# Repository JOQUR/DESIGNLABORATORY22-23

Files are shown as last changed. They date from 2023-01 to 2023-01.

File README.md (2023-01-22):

# DesignLab-BabaJaga
Repository for BabaJaga project created as part of Design Laboratory Classes
Welcome

BabaJaga Rules:
------------------
* 1. Participants:
For each game we need at least 3 participants, two players, and oone supervisor, which will start, and stop game
* 2. Duration
1min-3min for each round
* 3. How to Play?:
Supervisor using his mobile phone sets the game. Players have to stand in front of PIRs in the same distane, to give each players equal chances.
Then the game starts. Supervisor can use feature "Baba Jaga patrzy". At this moments players cannot move, if anyone moves, he loses round.
After reaching game board, player have to press the button. Then the game stops, and we have a winner.

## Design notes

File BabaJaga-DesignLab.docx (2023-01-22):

| AGH University of Science and Technology

Report on the project

Baba Jaga patrzy

For classes

Design Laboratory

Elektronika i Telekomunikacja, 3rd year

Paweł, Kierzek, Paweł Tymoczko, Mariusz Furtek

Coordinator: Dr inż. Jacek Stępień

22.01.2023

# 1. Project’s goal

Goal of the project was to create hardware-software system which is the implementation of the real-life game “Baba Jaga Patrzy”.

# 2. Design assumptions

  2.1. System functionality

Game system is divided into 2 modules communicating via common Bluetooth interface:

- Game Module - core of the game, if initialized can be in 2 states:
  - BABA_JAGA_PATRZY – detects players movement and reports it,
  - BABA_JAGA_NIE_PATRZY – detects pushed buttons and reports it.
- Control Module – allows to send 4 different messages to the Game Module START, STOP, BABA_JAGA_PATRZY, BABA_JAGA_NIE_PATRZY. Depending on the message type specified action are taken by another module:
  - START – initialize the game,
  - STOP – finish the game,
  - BABA_JAGA_PATRZY – change the game to “BABA_JAGA_PATRZY” state,
  - BABA_JAGA_NIE_PATRZY - change the game to “BABA_JAGA_NIE_ PATRZY” state.

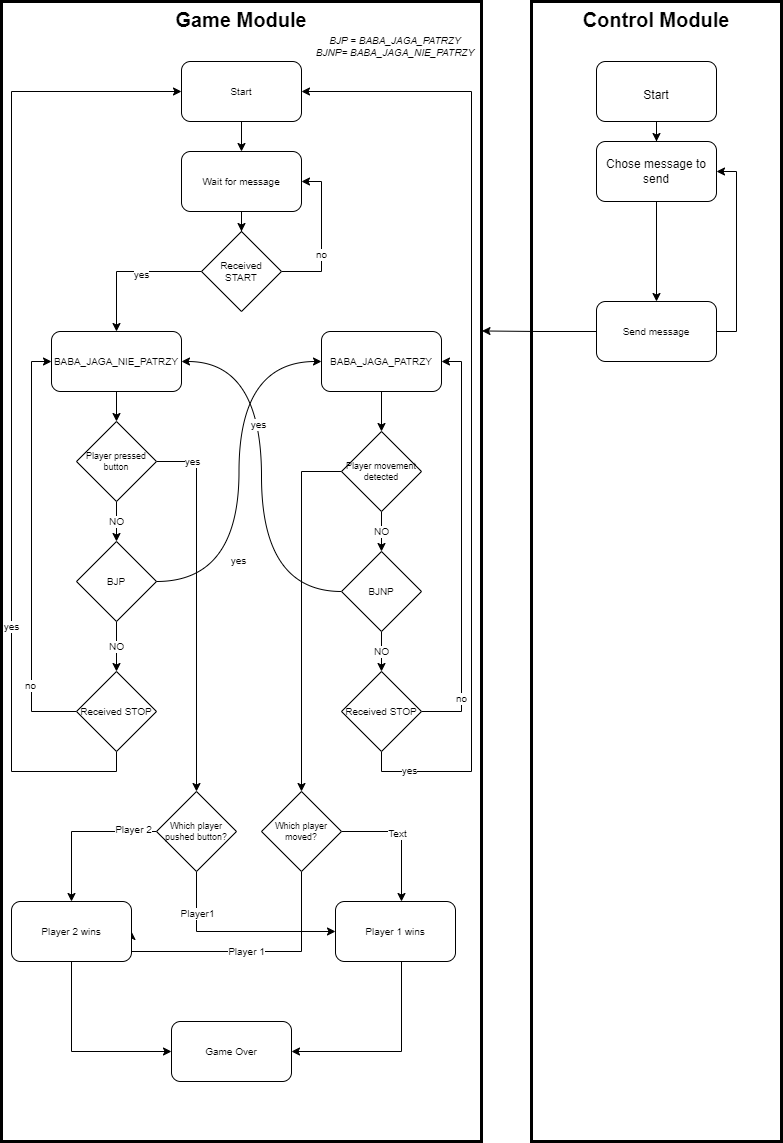
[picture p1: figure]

Picture 1. Game mechanism block diagram.

  2.2. User Interface

The game is designed for 3 players: 2 contestants and a game master.

The game master is responsible for controlling the game flow: starting/stopping the game and enabling/disabling movement detection.

If game master initializes the game, green diode lights up and keep on until the end of the game.

Contestant’s goal is to arrive to the location of the button and to push it before another player – first to do so wins. Contestant must watch out for the state of red diode. If it lights up, both players must stop and do not move. Otherwise, the contestant whose movement is detected, loses.

After player pushing the button or sensors detecting movement, high pitch sound is to be heard. One of two diodes (yellow corresponding to player no1 and green for player 2) lights up to inform who is the game winner.

  2.3. Hardware

Table 1. Electronic elements chosen for project implementation.

Element name | Module | Application
STM32 NUCLEO-L432KC | Game Module | Controls game flow, PIR movement detectors and all other game peripherals (buzzer, diodes), receives data from HC06 Bluetooth module
FRDM-KL05ZJ | Control Module | Sends messages to Bluetooth module HC05, based on pressed buttons, displays data on lcd
HC-05 BLUETOOTH MODULE | Control Module | Master of Bluetooth communication, transmit messages from Control Module to Game Module
HC-06 BLUETOOTH MODULE | Game Module | Slave of Bluetooth communication, receive messages from Control Module
HC-SR501 PIR MOTION DETECTOR | Game Module | Detects movement when Game Module is in BABA_JAGA_PATRZY state and reports game rules violation
HCM12-X BUZZER | Game module | Plays sound when game ends
LCD1602A (with I2C expander) | Control Module | Displays messages, currently transmitted to Game Module
HW-834 4x4 BUTTON MATRIX | Control Module | Pressing button corresponds to sending predefined messages

Datasheets of elements are to be found in project’s Git repository. Apart from listed components, other such as diodes, push button and resistors were used.

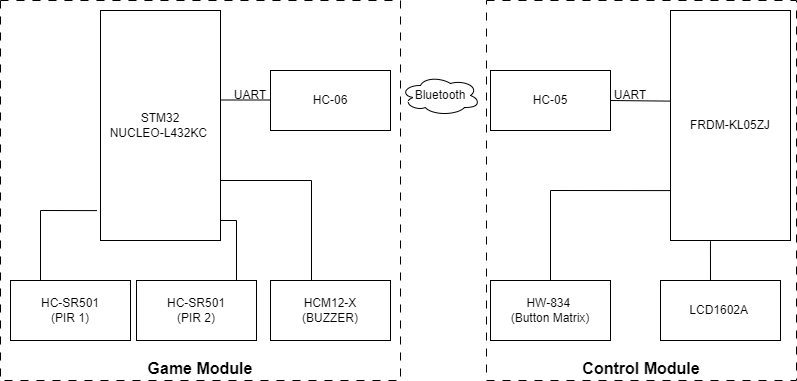
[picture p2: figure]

Picture 2. Project’s modules block diagram.

  2.4. Software Main functionality of Control Module’s program is to handle button matrix interrupts and transmit messages over UART to HC-05 Bluetooth module.

Game module’s program:

- handles interrupts from PIRs which detects players’ movement,
- lights up appropriate diode to inform players about game status,
- receives messages over UART form HC-06 and based on the input turns on or off PIRs’ interrupts.

Both Game Module and Control Module application were chosen to be written in C, using STM32CubeIDE.

# 3. Project Realization

Both modules have been designed according to presumptions described in previous part 2. Design assumptions. However, during integration process issue concerning HC05 and HC06 modules has occurred. There has been problem with entering command mode on Bluetooth modules, thus with pairing device for wireless communication. To mitigate impact on whole project and to ensure feature of wireless game controlling, new solution has been proposed: to substitute intended Control Module with simple mobile android application.

Created app has all assumed functionality and from user perspective is easier to use.

  3.1. Game Module’s electronic schematic and PCB layout

Game Module’s elements were connected according to the schematic in the Picture 3.

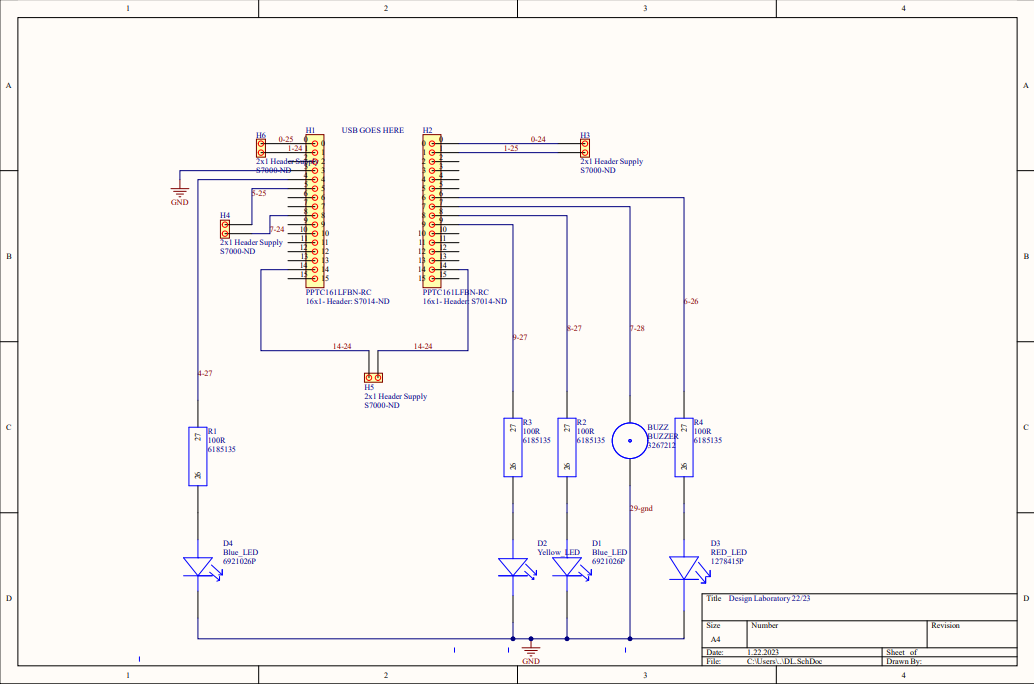
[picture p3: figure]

Picture 3. Game Module electronic schematic

On the schematic both PIRs and push buttons power on have not been put. PIRs are powered on according to the datasheet specification to +5V and GND and push buttons are connected to the power supply +5V.

Based on the electronic schematic attempt at creating PCB layout has been made. Unfortunately, created layout correctness has not been confirmed with necessary analysis.

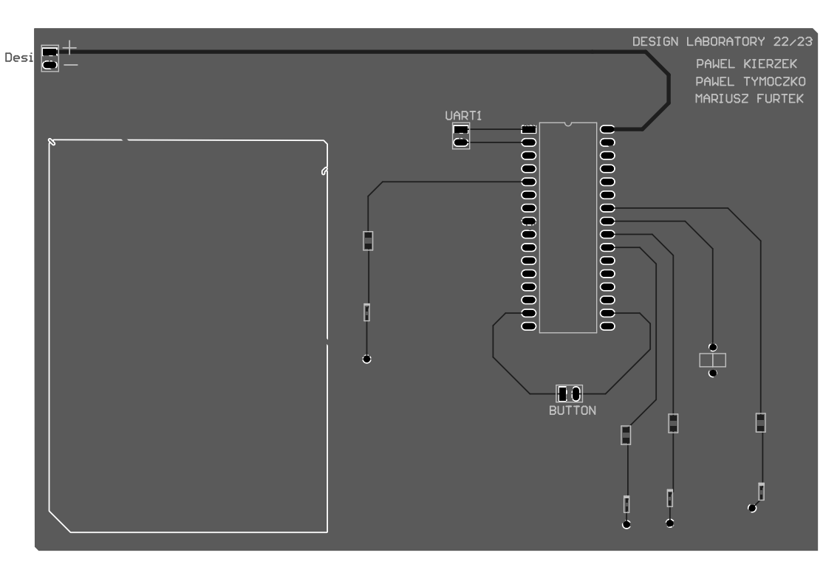
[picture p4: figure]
Obraz zawierający tekst, sprzęt elektroniczny Opis wygenerowany automatycznie

Picture 4. PCB Layout attempt

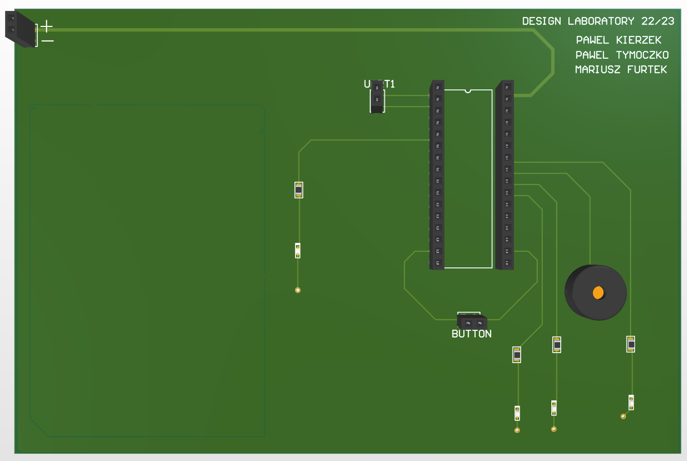
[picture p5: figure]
Brak opisu.

Picture 5. Expected frontside PCB 3D visualization.

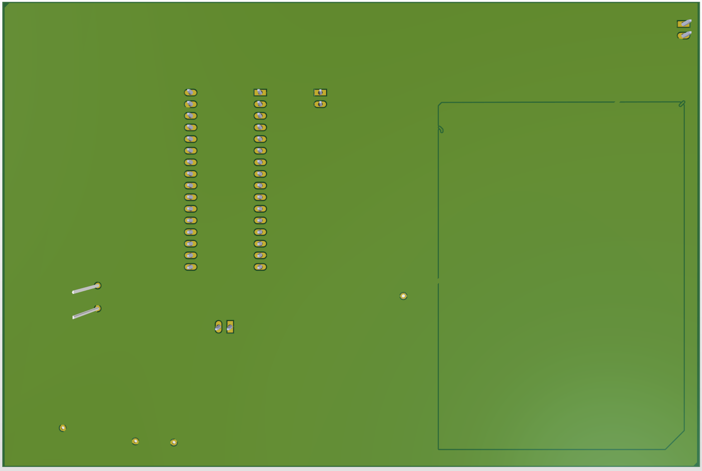
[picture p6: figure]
Brak opisu.

Picture 6. Expected backside PCB 3D visualization.

  3.2. Game module software

Table 2. Used GPIO pins, their configuration mode and functionality.

Pin name | User labels | Mode | Function
PB0 | PIR_SIG1 | External Interrupt Mode with rising edge trigger detection | Receives information about detected movement by PIR1
PB1 | PIR_SIG2 | External Interrupt Mode with rising edge trigger detection | Receives information about detected movement by PIR2
PA3 | PIR_OUT1 | Output Push Pull | Lights up yellow diode if player 1 wins
PA4 | PIR_OUT2 | Output Push Pull | Lights up green diode if player 2 wins
PA6 | BABA_JAGA_PATRZY | Output Push Pull | Lights up red diode if Game Module is in BABA_JAGA_PATRZY mode
PA5 | BUZZER | Output Push Pull | Generate sound if game finishes
PA12 | GAME_ON | Output Push Pull | Lights up green diode when game is initialized
PA10 | USART1_RX | UART | Enables Bluetooth communication with Control Module
PA9 | USART1_TX | UART
PB3 | BUTTON_1 | External Interrupt Mode with rising edge trigger detection | Receives information if player no. 1 pressed button
PB4 | BUTTON_2 | External Interrupt Mode with rising edge trigger detection | Receives information if player no. 2 pressed button

All pins above are configured to the appropriate mode and initialized in Game Module program’s main function.

In the program game loop, program is waiting for new messages from UART1. If new message is the same as one of defined below, it takes corresponding action:

- START – ‘A’: initializes the game, reset all diode pins and buzzer pin, clear players’ score, light up GAME_ON diode, set state to BABA_JAGA_NIE_PATRZY,
- STOP – ‘B’: finishes game, reset all diode pins and buzzer pin, clear players’ score,
- BABA_JAGA_PATRZY – ‘C’: enables PIRs interrupts to allow movement detection,
- BABA_JAGA_NIE_PATRZY – ‘D’: disable PIRs interrupts,
  3.3. Control Module mobile application

The application has been created using MIT App Inventor online tool in Scratch programming language. It allows to communicate with HC-05 module and send defined Game Module messages.

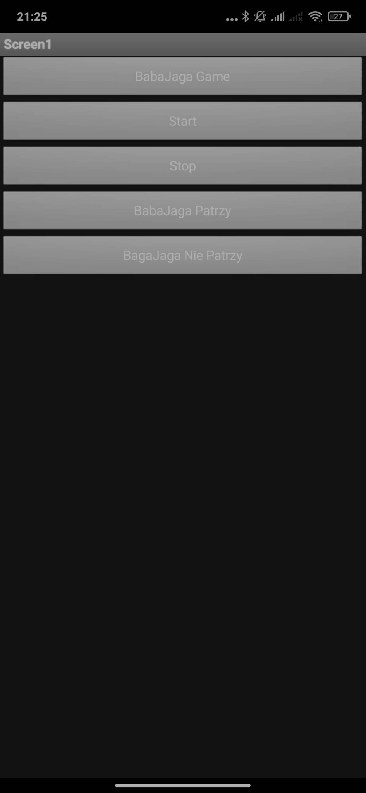
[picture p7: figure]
Brak opisu.

Picture 7. Screen shot of Control Module App GUI

  3.4. Workflow and labor division

The project’s workflow and labor division are to be found in the spreadsheet named workflow.xslx in git repository.

For project management and team organization Trello Kanban board was used.

# 4. Resources

  4.1. Project resources
- GIT repository: https://github.com/Pawlicho/DesignLab-BabaJaga
- Trello Kanban board: https://trello.com/b/rw4OTdqo/baba-jaga-patrzy
  4.2. External sources
- MIT App Inventor: https://appinventor.mit.edu/
- CAD footprints: https://www.digikey.pl/

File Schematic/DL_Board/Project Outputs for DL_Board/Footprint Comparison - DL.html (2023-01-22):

Altium customize

# Footprint Comparison Report

Date: | | 22.01.2023
Time: | | 23:47:13
Elapsed Time: | | 00:00:00
Filename: | | C:\Users\PKier\OneDrive\Pulpit\Design Lab\DesignLab-BabaJaga\Schematic\DL_Board\DL.PcbDoc

## Contents

Contents

Components Status Summary

Matched Components List

Missing PCB Components List

## Components Status Summary

## Matched Components List

Designator | Footprint | Footprint reference | Footprint to reference Library
Designator8 | DIP32 | DIP32 | C:\Users\PKier\OneDrive\Pulpit\Design Lab\DesignLab-BabaJaga\Schematic\DL_Board\DL.PcbLib
Designator9 | R0805 | R0805 | C:\Users\PKier\OneDrive\Pulpit\Design Lab\DesignLab-BabaJaga\Schematic\DL_Board\DL.PcbLib
Designator10 | R0805 | R0805 | C:\Users\PKier\OneDrive\Pulpit\Design Lab\DesignLab-BabaJaga\Schematic\DL_Board\DL.PcbLib
Designator11 | R0805 | R0805 | C:\Users\PKier\OneDrive\Pulpit\Design Lab\DesignLab-BabaJaga\Schematic\DL_Board\DL.PcbLib
Designator12 | R0805 | R0805 | C:\Users\PKier\OneDrive\Pulpit\Design Lab\DesignLab-BabaJaga\Schematic\DL_Board\DL.PcbLib
Designator13 | LED_BLUE | LED_BLUE | C:\Users\PKier\OneDrive\Pulpit\Design Lab\DesignLab-BabaJaga\Schematic\DL_Board\DL.PcbLib
Designator14 | LED_BLUE | LED_BLUE | C:\Users\PKier\OneDrive\Pulpit\Design Lab\DesignLab-BabaJaga\Schematic\DL_Board\DL.PcbLib
Designator15 | LED_Yellow | LED_Yellow | C:\Users\PKier\OneDrive\Pulpit\Design Lab\DesignLab-BabaJaga\Schematic\DL_Board\DL.PcbLib
Designator16 | LED_GREEN | LED_GREEN | C:\Users\PKier\OneDrive\Pulpit\Design Lab\DesignLab-BabaJaga\Schematic\DL_Board\DL.PcbLib
Designator17 | BUZZ | BUZZ | C:\Users\PKier\OneDrive\Pulpit\Design Lab\DesignLab-BabaJaga\Schematic\DL_Board\DL.PcbLib
Designator18 | Power | Power | C:\Users\PKier\OneDrive\Pulpit\Design Lab\DesignLab-BabaJaga\Schematic\DL_Board\DL.PcbLib
Designator20 | Power | Power | C:\Users\PKier\OneDrive\Pulpit\Design Lab\DesignLab-BabaJaga\Schematic\DL_Board\DL.PcbLib
Designator21 | Power | Power | C:\Users\PKier\OneDrive\Pulpit\Design Lab\DesignLab-BabaJaga\Schematic\DL_Board\DL.PcbLib

Back to top

## Missing PCB Components List

Designator | Footprint | Footprint reference | Path to reference Library
BUZZ | | BUZZ | C:\Users\PKier\OneDrive\Pulpit\Design Lab\DesignLab-BabaJaga\Schematic\DL_Board\DL.PcbLib
D1 | | LED_BLUE | C:\Users\PKier\OneDrive\Pulpit\Design Lab\DesignLab-BabaJaga\Schematic\DL_Board\DL.PcbLib
D2 | | LED_Yellow | C:\Users\PKier\OneDrive\Pulpit\Design Lab\DesignLab-BabaJaga\Schematic\DL_Board\DL.PcbLib
D3 | | LED_GREEN | C:\Users\PKier\OneDrive\Pulpit\Design Lab\DesignLab-BabaJaga\Schematic\DL_Board\DL.PcbLib
D4 | | LED_BLUE | C:\Users\PKier\OneDrive\Pulpit\Design Lab\DesignLab-BabaJaga\Schematic\DL_Board\DL.PcbLib
H1 | | DIP32 | C:\Users\PKier\OneDrive\Pulpit\Design Lab\DesignLab-BabaJaga\Schematic\DL_Board\DL.PcbLib
H2 | | DIP32 | C:\Users\PKier\OneDrive\Pulpit\Design Lab\DesignLab-BabaJaga\Schematic\DL_Board\DL.PcbLib
H3 | | Power | C:\Users\PKier\OneDrive\Pulpit\Design Lab\DesignLab-BabaJaga\Schematic\DL_Board\DL.PcbLib
H4 | | Power | C:\Users\PKier\OneDrive\Pulpit\Design Lab\DesignLab-BabaJaga\Schematic\DL_Board\DL.PcbLib
H5 | | Power | C:\Users\PKier\OneDrive\Pulpit\Design Lab\DesignLab-BabaJaga\Schematic\DL_Board\DL.PcbLib
H6 | | Power | C:\Users\PKier\OneDrive\Pulpit\Design Lab\DesignLab-BabaJaga\Schematic\DL_Board\DL.PcbLib
R1 | | R0805 | C:\Users\PKier\OneDrive\Pulpit\Design Lab\DesignLab-BabaJaga\Schematic\DL_Board\DL.PcbLib
R2 | | R0805 | C:\Users\PKier\OneDrive\Pulpit\Design Lab\DesignLab-BabaJaga\Schematic\DL_Board\DL.PcbLib
R3 | | R0805 | C:\Users\PKier\OneDrive\Pulpit\Design Lab\DesignLab-BabaJaga\Schematic\DL_Board\DL.PcbLib
R4 | | R0805 | C:\Users\PKier\OneDrive\Pulpit\Design Lab\DesignLab-BabaJaga\Schematic\DL_Board\DL.PcbLib

Back to top

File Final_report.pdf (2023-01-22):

# AGH University of Science and Technology

# Report on the project

# Baba Jaga patrzy

# For classes

# Design Laboratory

## Elektronika i Telekomunikacja, 3

## rd year

## Paweł, Kierzek, Paweł Tymoczko, Mariusz Furtek

Coordinator: Dr inż. Jacek Stępień

22.01.2023

## 1. Project’s goal

Goal of the project was to create hardware-software system which is the implementation of the real-life game “Baba Jaga Patrzy”.

## 2. Design assumptions

### 2.1. System functionality

Game system is divided into 2 modules communicating via common Bluetooth interface:

- Game Module - core of the game, if initialized can be in 2 states:
- BABA_JAGA_PATRZY – detects players movement and reports it,
- BABA_JAGA_NIE_PATRZY – detects pushed buttons and reports it.
- Control Module – allows to send 4 different messages to the Game Module START, STOP,

BABA_JAGA_PATRZY, BABA_JAGA_NIE_PATRZY. Depending on the message type

specified action are taken by another module:

- START – initialize the game,
- STOP – finish the game,
- BABA_JAGA_PATRZY – change the game to “BABA_JAGA_PATRZY” state,
- BABA_JAGA_NIE_PATRZY - change the game to “BABA_JAGA_NIE_ PATRZY”

state.


Picture 1. Game mechanism block diagram.

### 2.2. User Interface

The game is designed for 3 players: 2 contestants and a game master.

The game master is responsible for controlling the game flow: starting/stopping the game and

enabling/disabling movement detection.

If game master initializes the game, green diode lights up and keep on until the end of the game.

Contestant’s goal is to arrive to the location of the button and to push it before another player – first to do so wins. Contestant must watch out for the state of red diode. If it lights up, both players must

stop and do not move. Otherwise, the contestant whose movement is detected, loses.

After player pushing the button or sensors detecting movement, high pitch sound is to be heard. One

of two diodes (yellow corresponding to player no1 and green for player 2) lights up to inform who is the game winner.

### 2.3. Hardware

Table 1. Electronic elements chosen for project implementation.

Element name | Module | Application
STM32 NUCLEO-L432KC | Game Module | Controls game flow, PIR movement detectors and all other game peripherals (buzzer, diodes), receives data from HC06 Bluetooth module
FRDM-KL05ZJ | Control Module | Sends messages to Bluetooth module HC05, based on pressed buttons, displays data on lcd
HC-05 BLUETOOTH MODULE | Control Module | Master of Bluetooth communication, transmit messages from Control Module to Game Module
HC-06 BLUETOOTH MODULE | Game Module | Slave of Bluetooth communication, receive messages from Control Module
HC-SR501 PIR MOTION DETECTOR | Game Module | Detects movement when Game Module is in BABA_JAGA_PATRZY

| | state and reports game rules violation
HCM12-X BUZZER | Game module | Plays sound when game ends
LCD1602A (with I2C expander) | Control Module | Displays messages, currently transmitted to Game Module
HW-834 4x4 BUTTON MATRIX | Control Module | Pressing button corresponds to sending predefined messages

Datasheets of elements are to be found in project’s Git repository. Apart from listed components, other such as diodes, push button and resistors were used.

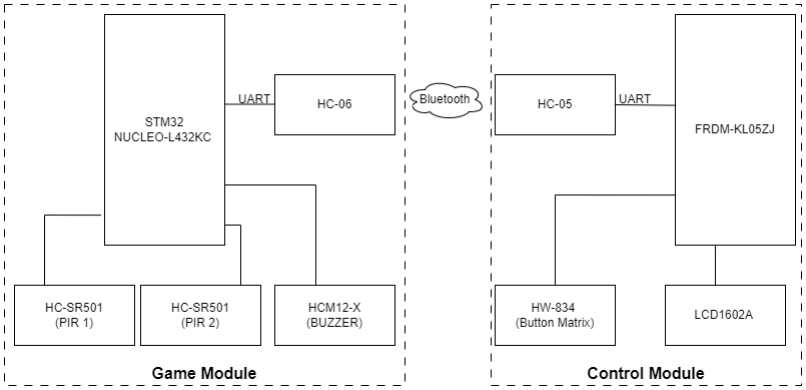
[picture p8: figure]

Picture 2. Project’s modules block diagram.

2.4. Software
Main functionality of Control Module’s program is to handle button matrix interrupts and transmit

messages over UART to HC-05 Bluetooth module.

Game module’s program:

- handles interrupts from PIRs which detects players’ movement,
- lights up appropriate diode to inform players about game status,
- receives messages over UART form HC-06 and based on the input turns on or off PIRs’

interrupts.

Both Game Module and Control Module application were chosen to be written in C, using STM32CubeIDE.

## 3. Project Realization

Both modules have been designed according to presumptions described in previous part 2. Design assumptions. However, during integration process issue concerning HC05 and HC06 modules has occurred. There has been problem with entering command mode on Bluetooth modules , thus with pairing device for wireless communication. To mitigate impact on whole project and to ensure feature of wireless game controlling, new solution has been proposed: to substitute intended Control Module with simple mobile android application.

Created app has all assumed functionality and from user perspective is easier to use.

### 3.1. Game Module’s electronic schematic and PCB layout

Game Module’s elements were connected according to the schematic in the Picture 3.


Picture 3. Game Module electronic schematic

On the schematic both PIRs and push buttons power on have not been put. PIRs are powered on according to the datasheet specification to +5V and GND and push buttons are connected to the power supply +5V.

Based on the electronic schematic attempt at creating PCB layout has been made. Unfortunately,
created | layout | correctness | has | not | been | confirmed | with | necessary | analysis.


Picture 4. PCB Layout attempt

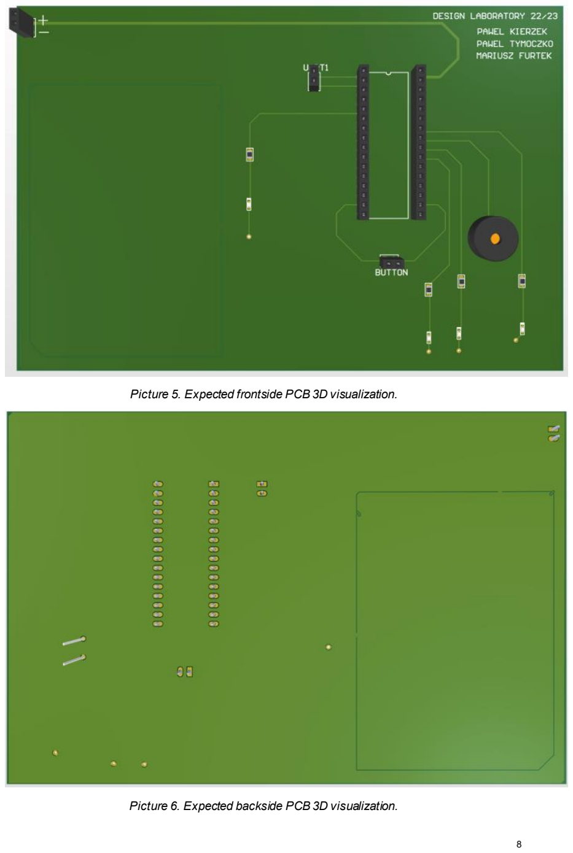
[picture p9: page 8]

Picture 5. Expected frontside PCB 3D visualization.

Picture 6. Expected backside PCB 3D visualization.

3.2. Game module software

Table 2. Used GPIO pins, their configuration mode and functionality.

Pin name | User labels | Mode | Function
PB0 | PIR_SIG1 | External Interrupt Mode with rising edge trigger detection | Receives information about detected movement by PIR1
PB1 | PIR_SIG2 | External Interrupt Mode with rising edge trigger detection | Receives information about detected movement by PIR2
PA3 | PIR_OUT1 | Output Push Pull | Lights up yellow diode if player 1 wins
PA4 | PIR_OUT2 | Output Push Pull | Lights up green diode if player 2 wins
PA6 | BABA_JAGA_PATRZY | Output Push Pull | Lights up red diode if Game Module is in BABA_JAGA_PATRZY mode
PA5 | BUZZER | Output Push Pull | Generate sound if game finishes
PA12 | GAME_ON | Output Push Pull | Lights up green diode when game is initialized
PA10 | USART1_RX | UART | Enables Bluetooth communication with
| USART1_TX | UART | Control Module PA9
PB3 | BUTTON_1 | External Interrupt Mode with rising edge trigger detection | Receives information if player no. 1 pressed button
PB4 | BUTTON_2 | External Interrupt Mode with rising edge trigger detection | Receives information if player no. 2 pressed button

All pins above are configured to the appropriate mode and initialized in Game Module program’s main function.

In the program game loop, program is waiting for new messages from UART1. If new message is the same as one of defined below, it takes corresponding action:

- START – ‘A’: initializes the game, reset all diode pins and buzzer pin, clear players’ score, light up GAME_ON diode, set state to BABA_JAGA_NIE_PATRZY,
- STOP – ‘B’: finishes game, reset all diode pins and buzzer pin, clear players’ score,

- BABA_JAGA_PATRZY – ‘C’: enables PIRs interrupts to allow movement detection,
- BABA_JAGA_NIE_PATRZY – ‘D’: disable PIRs interrupts,
3.3. Control Module mobile application

The application has been created using MIT App Inventor online tool in Scratch programming language. It allows to communicate with HC-05 module and send defined Game Module messages.

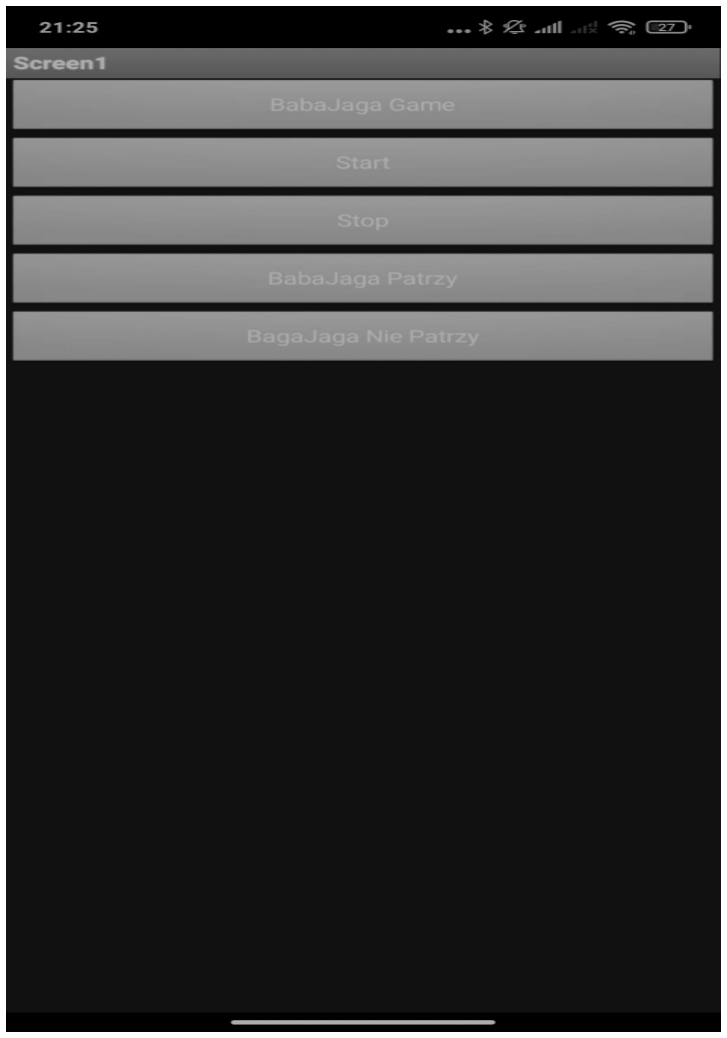
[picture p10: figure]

Picture 7. Screen shot of Control Module App GUI

3.4. Workflow and labor division

The project’s workflow and labor division are to be found in the spreadsheet named workflow.xslx in git repository.

For project management and team organization Trello Kanban board was used.

## 4. Resources

4.1. Project resources

- GIT repository: https://github.com/Pawlicho/DesignLab-BabaJaga
- Trello Kanban board: https://trello.com/b/rw4OTdqo/baba-jaga-patrzy
4.2. External sources
- MIT App Inventor: https://appinventor.mit.edu/
- CAD footprints: https://www.digikey.pl/

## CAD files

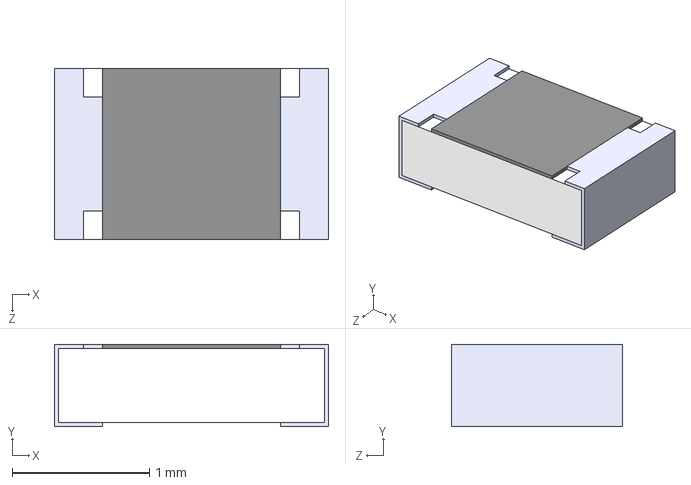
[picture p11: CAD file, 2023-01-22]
Schematic/DL_Board/RC0805FR-07100RL (1).STEP
2.00 x 0.6 x 1.25 mm

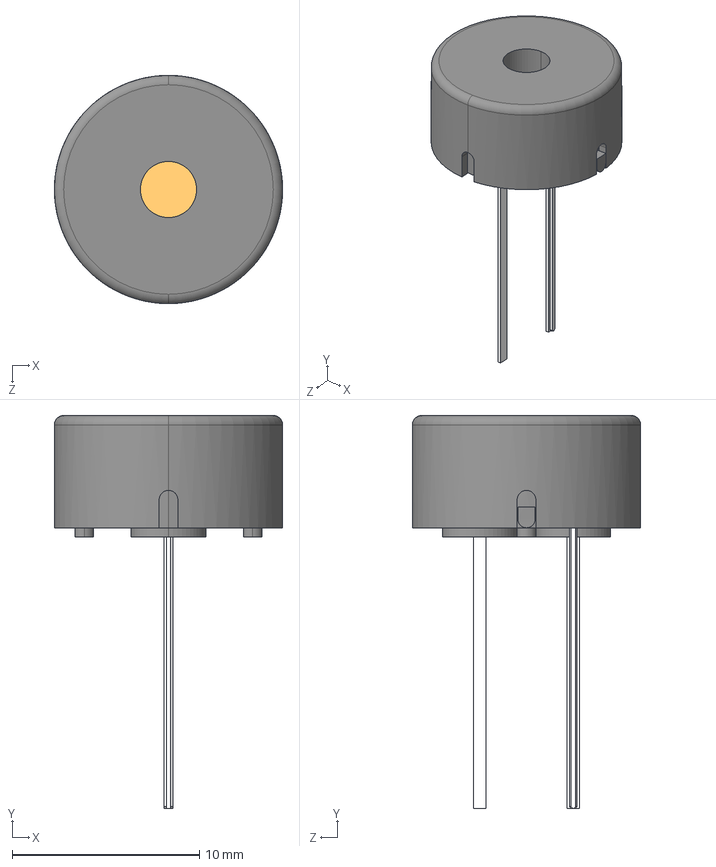
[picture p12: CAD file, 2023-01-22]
Schematic/DL_Board/PS1240P02BT--3DModel-STEP-56544.STEP
12.2 x 21.0 x 12.2 mm

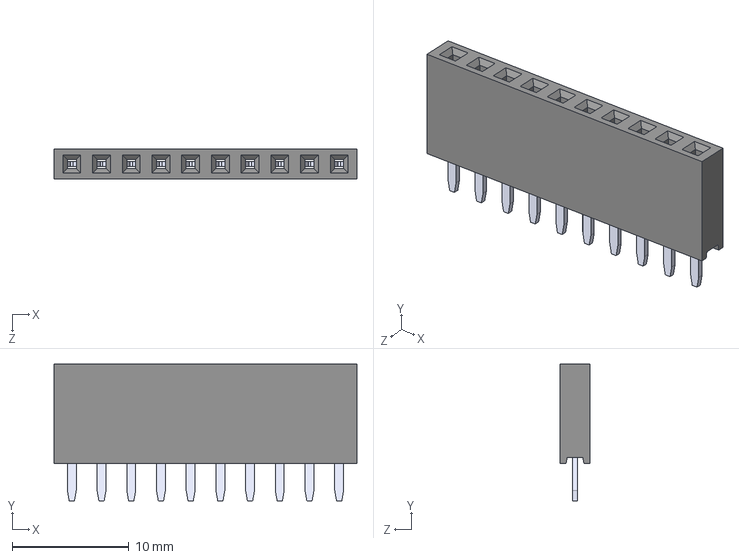
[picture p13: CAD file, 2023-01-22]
Schematic/DL_Board/PPTC101LFBN-RC--3DModel-STEP-56544.STEP
25.9 x 11.7 x 2.54 mm

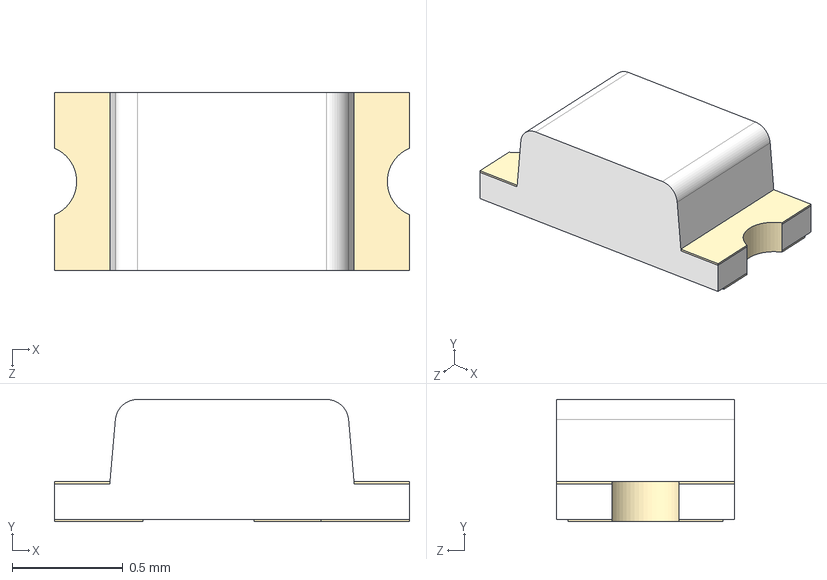
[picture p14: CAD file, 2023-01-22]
Schematic/DL_Board/LTST-C191KRKT.STEP
1.60 x 0.55 x 0.8 mm

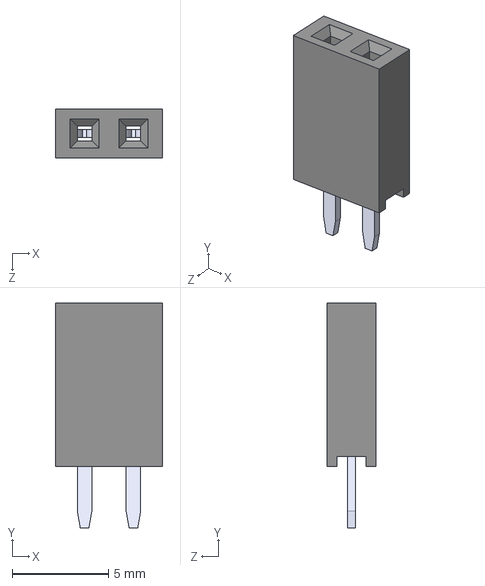
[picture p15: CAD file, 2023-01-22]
Schematic/DL_Board/PPTC021LFBN-RC--3DModel-STEP-56544.STEP
5.59 x 11.7 x 2.54 mm

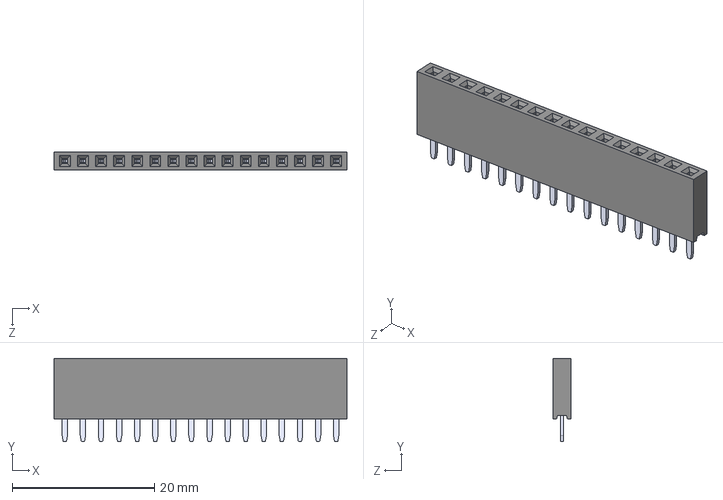
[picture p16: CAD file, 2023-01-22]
Schematic/DL_Board/PPTC161LFBN-RC--3DModel-STEP-56544.STEP
41.1 x 11.7 x 2.54 mm

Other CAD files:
Schematic/DL_Board/Project Outputs for DL_Board/DL_Board.PRT

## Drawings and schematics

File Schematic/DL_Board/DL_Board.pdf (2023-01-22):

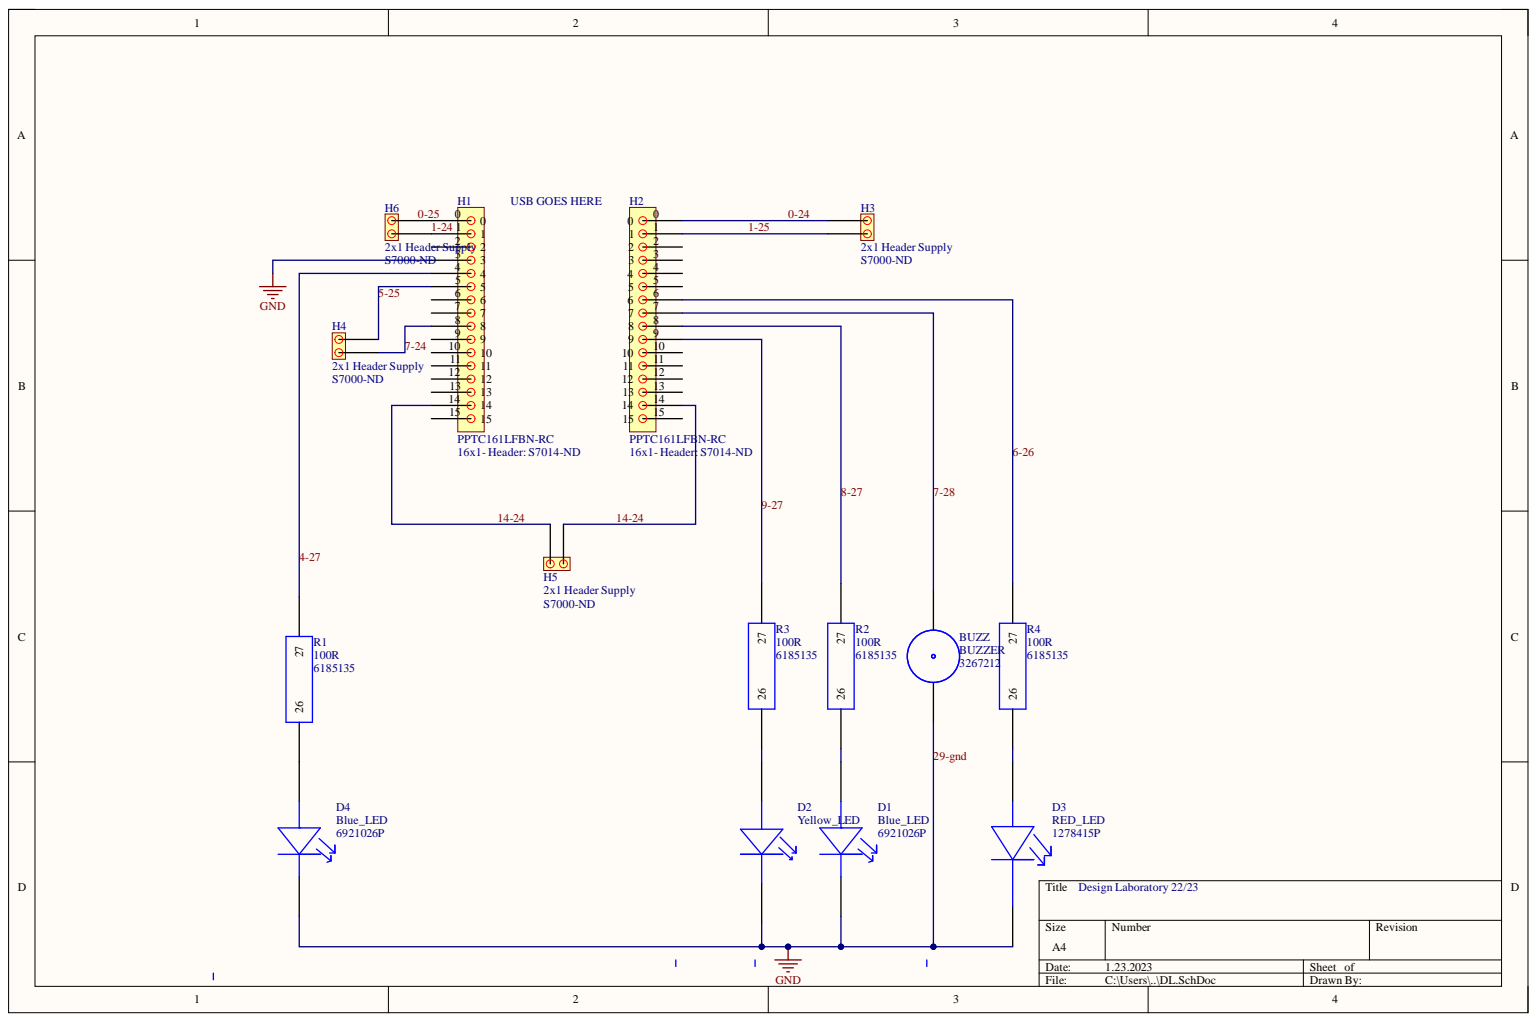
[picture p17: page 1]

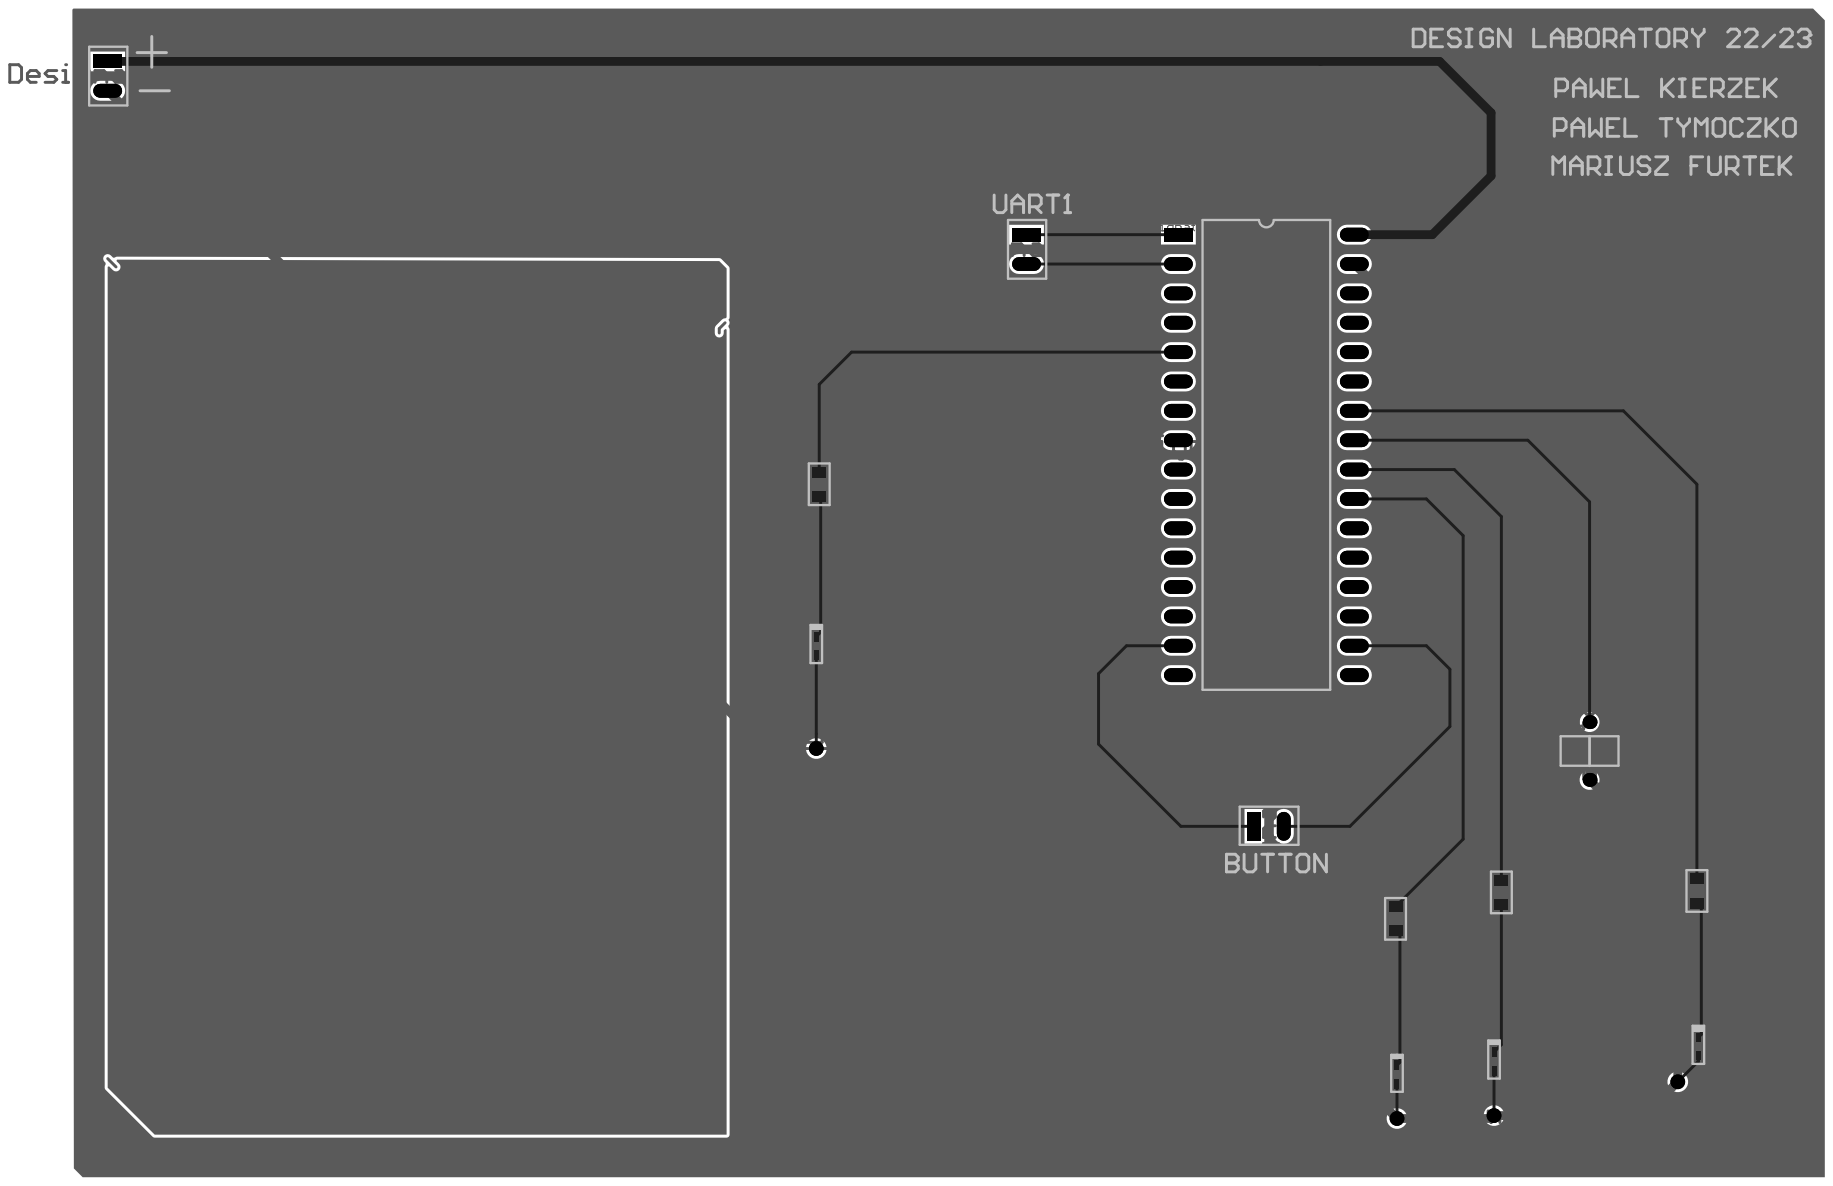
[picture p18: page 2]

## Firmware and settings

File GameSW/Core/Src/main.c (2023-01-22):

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
/* Includes ------------------------------------------------------------------*/
#include "main.h"
#include "usart.h"
#include "gpio.h"

/* USER CODE BEGIN Includes */
#include "player.h"
#include "debug_settings.h"
#include "game_if.h"
#include <string.h>
/* USER CODE END Includes */

/* USER CODE BEGIN PD */
#define START ('A')
#define STOP ('B')
#define BABA_JAGA_PATRZY ('C')
#define BABA_JAGA_NIE_PATRZY ('D')
/* USER CODE END PD */


/* USER CODE BEGIN PV */
extern struct Player player_one;
extern struct Player player_two;

/* USER CODE END PV */

void SystemClock_Config(void);
/**
  * @brief  The application entry point.
  * @retval int
  */
int main(void)
{
  /* USER CODE BEGIN 1 */
    NVIC_DisableIRQ(EXTI0_IRQn);
	NVIC_DisableIRQ(EXTI1_IRQn);
	NVIC_DisableIRQ(EXTI4_IRQn);
	NVIC_DisableIRQ(EXTI3_IRQn);
  /* USER CODE END 1 */

  /* MCU Configuration--------------------------------------------------------*/

  /* Reset of all peripherals, Initializes the Flash interface and the Systick. */
  HAL_Init();

  /* Configure the system clock */
  SystemClock_Config();

  /* Initialize all configured peripherals */
  MX_GPIO_Init();
  MX_USART1_UART_Init();
  /* USER CODE BEGIN 2 */
  int players_movement_allowed = 1;
  uint8_t message = '0';

  /* USER CODE END 2 */

  /* Infinite loop */
  /* USER CODE BEGIN WHILE */
  while (1)
  {
	  HAL_UART_Receive(&huart1, &message, 1, 150);

	  switch (message)
	  {
	  case START:
		  game_init();
		  players_movement_allowed = 1;
		  message = BABA_JAGA_NIE_PATRZY;
		  break;
	  case STOP:
		  end_game();
		  message = 0x00;
		  break;
	  case BABA_JAGA_PATRZY:
		  NVIC_EnableIRQ(EXTI0_IRQn);
		  NVIC_EnableIRQ(EXTI1_IRQn);
		  players_movement_allowed = 0;
		  message = 0x00;
		  break;
	  case BABA_JAGA_NIE_PATRZY:
		  NVIC_DisableIRQ(EXTI0_IRQn);
		  NVIC_DisableIRQ(EXTI1_IRQn);
		  players_movement_allowed = 1;
		  message = 0x00;
		  break;
	  default:
		  message = 0x00;
		  break;
	  }
	  if (players_movement_allowed == 0)
	  {
		  HAL_GPIO_WritePin(BABA_JAGA_PATRZY_GPIO_Port, BABA_JAGA_PATRZY_Pin, 1);

	  }
	  else
	  {
		  HAL_GPIO_WritePin(BABA_JAGA_PATRZY_GPIO_Port, BABA_JAGA_PATRZY_Pin, 0);
	  }
	  if (player_two.score == 1)
	  {
		  // Player 1 wins
		  HAL_GPIO_WritePin(PIR_OUT_1_GPIO_Port, PIR_OUT_1_Pin, 1);
		  HAL_GPIO_WritePin(BUZZER_GPIO_Port, BUZZER_Pin, 1);
		  HAL_Delay(2000);
		  players_movement_allowed = 1;
		  end_game();
		 }
	  else if (player_one.score == 1)
	  {
		  // Player 2 wins
		  HAL_GPIO_WritePin(PIR_OUT_2_GPIO_Port, PIR_OUT_2_Pin, 1);
		  HAL_GPIO_WritePin(BUZZER_GPIO_Port, BUZZER_Pin, 1);
		  HAL_Delay(2000);
		  players_movement_allowed = 1;
		  end_game();
	  }
    /* USER CODE END WHILE */

    /* USER CODE BEGIN 3 */
  }
  /* USER CODE END 3 */
}

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


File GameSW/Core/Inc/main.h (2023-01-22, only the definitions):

#define MCO_Pin GPIO_PIN_0
#define MCO_GPIO_Port GPIOA
#define VCP_TX_Pin GPIO_PIN_2
#define VCP_TX_GPIO_Port GPIOA
#define PIR_OUT_1_Pin GPIO_PIN_3
#define PIR_OUT_1_GPIO_Port GPIOA
#define PIR_OUT_2_Pin GPIO_PIN_4
#define PIR_OUT_2_GPIO_Port GPIOA
#define BUZZER_Pin GPIO_PIN_5
#define BUZZER_GPIO_Port GPIOA
#define BABA_JAGA_PATRZY_Pin GPIO_PIN_6
#define BABA_JAGA_PATRZY_GPIO_Port GPIOA
#define PIR_SIG_1_Pin GPIO_PIN_0
#define PIR_SIG_1_GPIO_Port GPIOB
#define PIR_SIG_1_EXTI_IRQn EXTI0_IRQn
#define PIR_SIG_2_Pin GPIO_PIN_1
#define PIR_SIG_2_GPIO_Port GPIOB
#define PIR_SIG_2_EXTI_IRQn EXTI1_IRQn
#define GAME_ON_Pin GPIO_PIN_12
#define GAME_ON_GPIO_Port GPIOA
#define SWDIO_Pin GPIO_PIN_13
#define SWDIO_GPIO_Port GPIOA
#define SWCLK_Pin GPIO_PIN_14
#define SWCLK_GPIO_Port GPIOA
#define VCP_RX_Pin GPIO_PIN_15
#define VCP_RX_GPIO_Port GPIOA
#define BUTTON_1_Pin GPIO_PIN_3
#define BUTTON_1_GPIO_Port GPIOB
#define BUTTON_1_EXTI_IRQn EXTI3_IRQn
#define BUTTON_2_Pin GPIO_PIN_4
#define BUTTON_2_GPIO_Port GPIOB
#define BUTTON_2_EXTI_IRQn EXTI4_IRQn
#define BUFFOR_MAX_SIZE (128)

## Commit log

2022-12-11 Add Project
    [AUE_Projekt_Zaliczeniowy.PrjPcb, Sheet1.SchDoc, Sheet2.SchDoc]
2023-01-16 Working uart receiving
2023-01-21 Raport - second attempt
    [workflow.xlsx]
2023-01-21 Found hole in Game module implementation & some docummentation update
2023-01-22 Added buttons
2023-01-22 Updated workflow
    [workflow.xlsx]
2023-01-22 Updated Layout
    [DESIGN_LAB.PrjPcb, DL.PcbDoc, DL_Board.PrjPcb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]

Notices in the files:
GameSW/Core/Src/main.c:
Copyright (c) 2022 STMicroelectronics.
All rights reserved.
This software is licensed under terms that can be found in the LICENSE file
